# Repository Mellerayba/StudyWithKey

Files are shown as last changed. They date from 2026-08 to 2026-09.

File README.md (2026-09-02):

# StudyWithKey

A custom Bluetooth LE macro remote for flashcard/study-app navigation —
built from a breadboard proof-of-concept through to a battery-powered
custom PCB.

## Status
Currently halted - critical flaw in the ordered PCBs and I am not in a financial position currently to reorder them.
Firmware is completely functional and available to use freely

## Roadmap
- [x] Prototype 1 — breadboard BLE HID proof of concept
- [x] Prototype 2 — custom PCB, USB-C + battery power, hardware complete, DRC clean, ordered
- [ ] Prototype 2 — enclosure (parametric CadQuery model, pending fit check against fabricated board)
- [x] Prototype 2 — firmware (FSM-based button handling, BLE HID)
- [ ] Prototype 3 — ULP RISC-V coprocessor deep-sleep refactor

## Roadmap Update
Sadly the ordered PCB's arrived with a fatal flaw, the switches were miss oriented - causing an internal short circuit. I managed to re - solder some switches 
however it is not viable to do this for the entire order. I am not currently in the financial position to continue this project
after such a set back; however, the firmware is completely functional and available to use on any ESP-32.

## Prototypes
- [Prototype 1: Breadboard](./Physical-Prototypes/README.md) — early proof that BLE HID pairing and keypresses work end to end
- [Prototype 2: Custom PCB](./prototype-2-custom-pcb/) — purpose-built board with USB-C, LiPo charging, and a real power path
- [Physical PCB: Resoldered demo](././Physical-Prototypes/PhysicalProduct.md) — Demo photos and videos of the real custom PCB, showing that the firmware works

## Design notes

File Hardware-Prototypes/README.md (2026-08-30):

# Custom PCB

## Initial PCB prototype

### Hardware Architecture

| Top-Down PCB Layout | 3D Board Preview | Schematic View
| :---: | :---: | :---: |
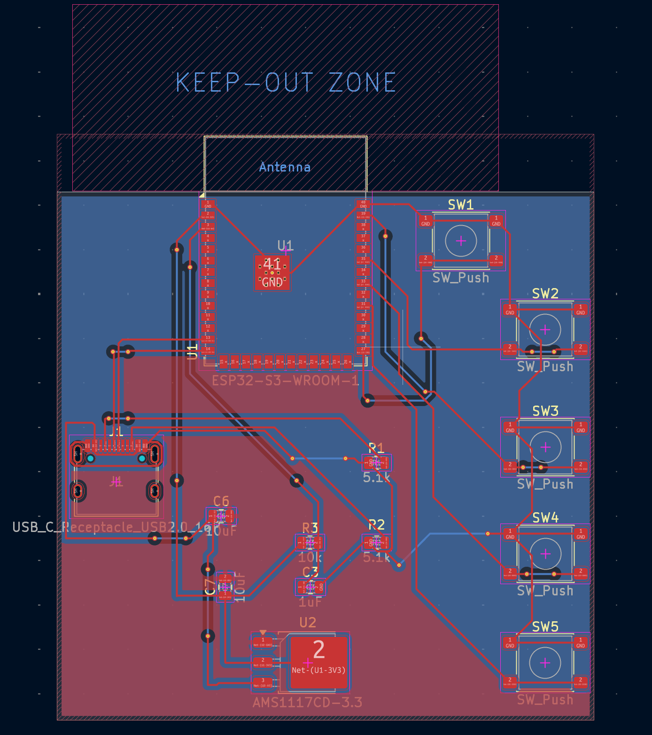
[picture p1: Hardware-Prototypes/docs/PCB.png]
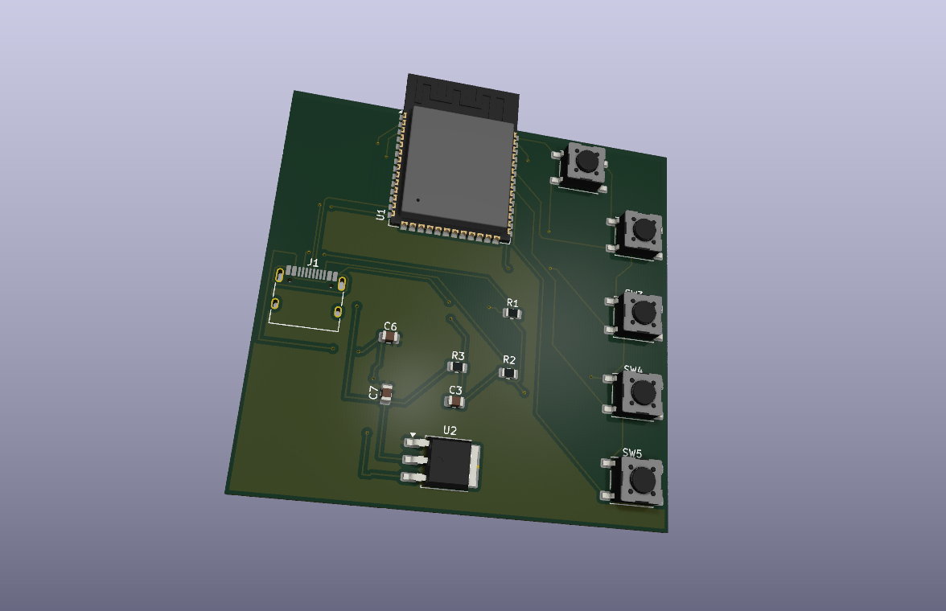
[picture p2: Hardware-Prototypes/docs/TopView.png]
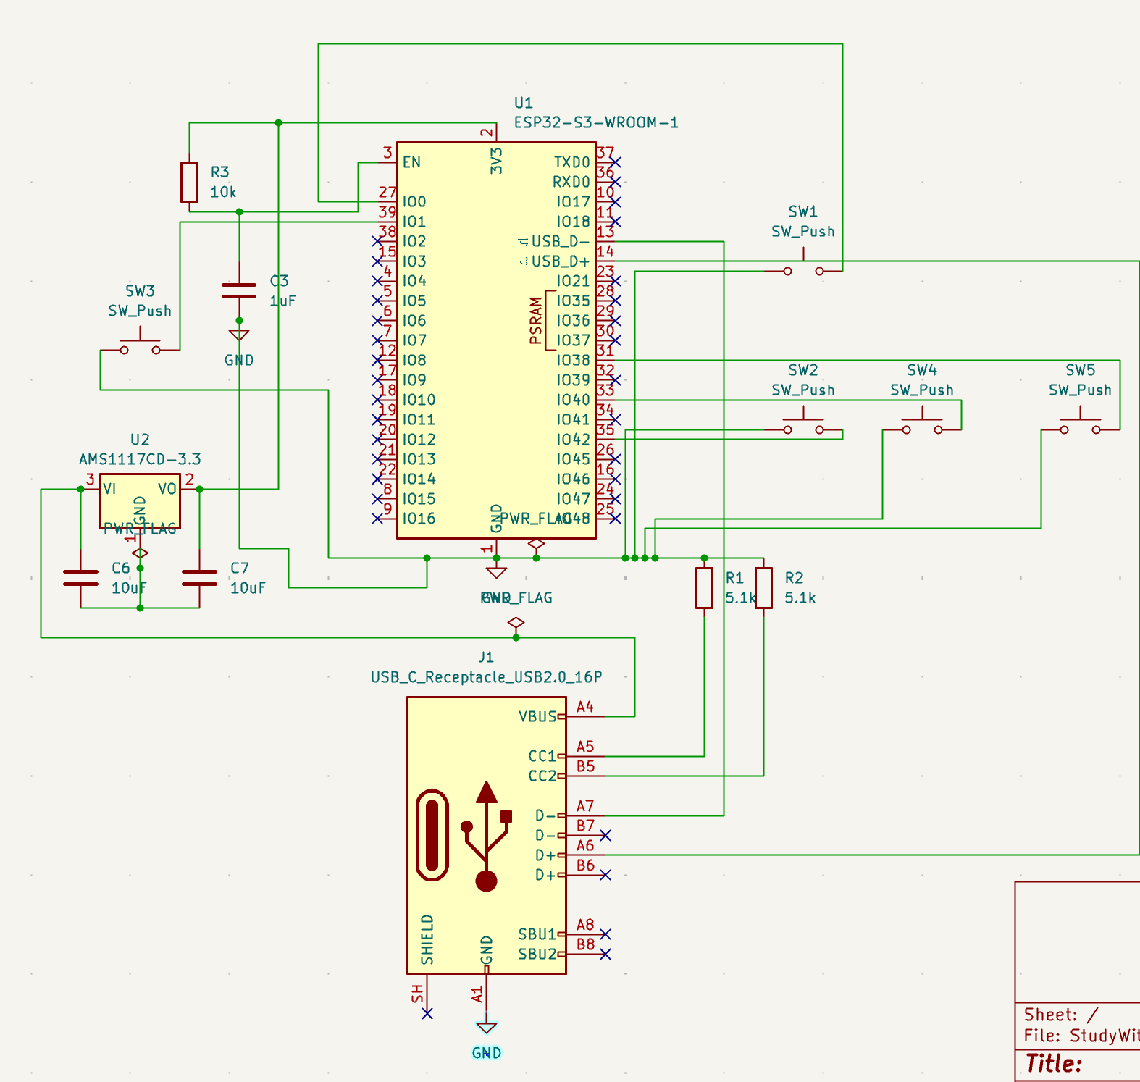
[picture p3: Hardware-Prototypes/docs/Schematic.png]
Schematic
|  |  | 

### Board Specifications
* **Processor:** ESP32-S3-WROOM-1 (Dual-Core Xtensa LX7 + ULP RISC-V Coprocessor)
* **Power Rail:** USB-C (5V) $\rightarrow$ AMS1117-3.3 LDO (3.3V rail with 10µF bulk filtering)
* **Input Matrix:** 5x Tactile Switches (Direct-mapped to RTC GPIOs for low-power deep-sleep wakeups)
* **PCB Constraints:** 2-layer FR-4, 1.6mm board thickness, 1 oz Cu, 0.3mm min via holes

## PCB Prototype 2

| Top-Down PCB Layout | 3D Board Preview | Schematic View
| :---: | :---: | :---: |
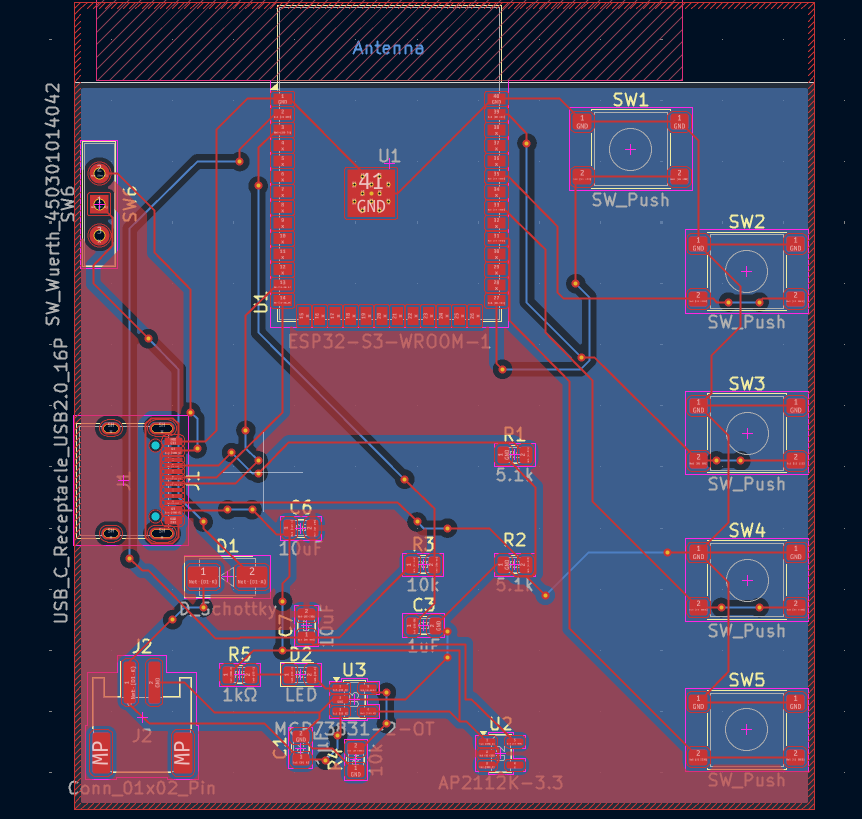
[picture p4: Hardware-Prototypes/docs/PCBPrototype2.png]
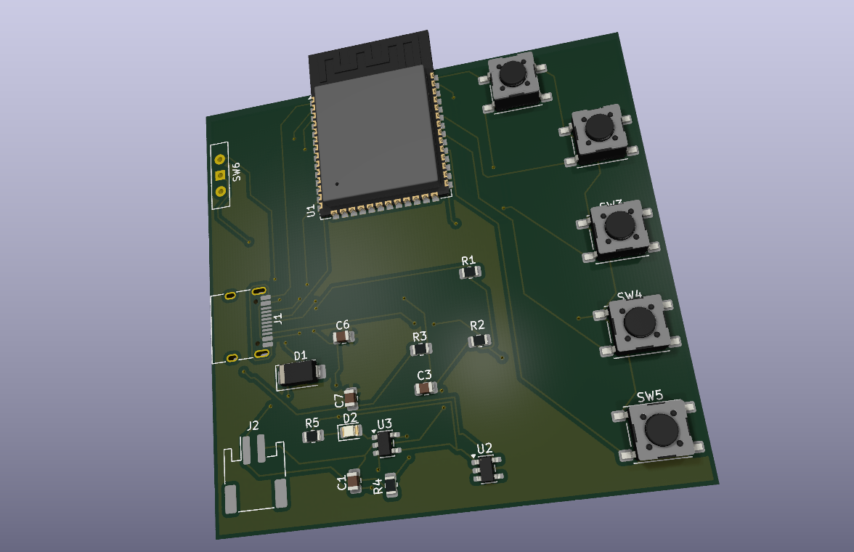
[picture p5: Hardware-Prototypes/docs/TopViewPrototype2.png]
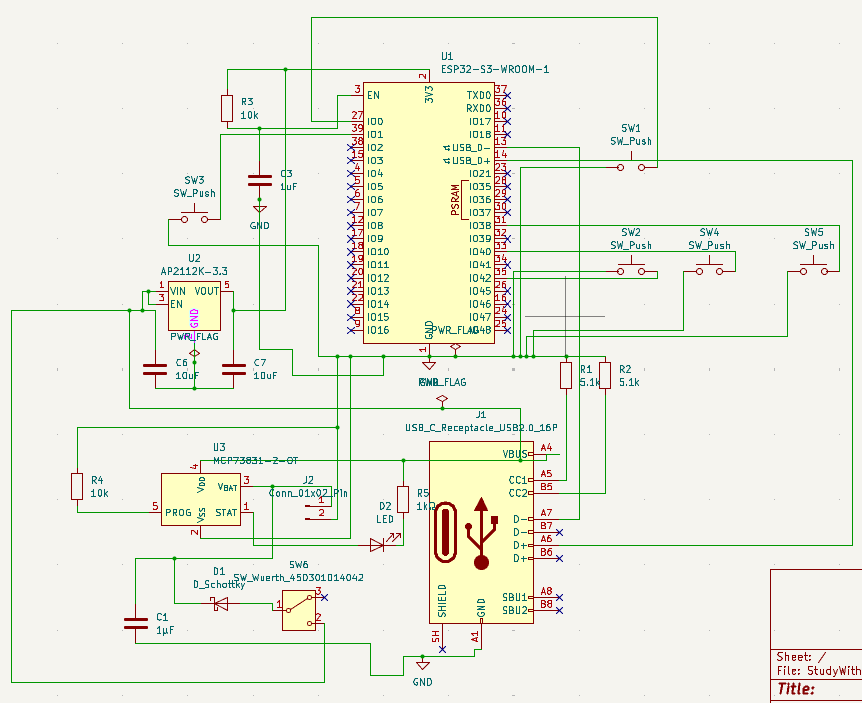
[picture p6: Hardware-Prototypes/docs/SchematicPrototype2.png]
Schematic
|  |  | 

## What changed from Prototype 1
- Custom KiCad schematic + PCB, built around the ESP32-S3-WROOM-1
- USB-C for power/data, with correct CC1/CC2 pull-down resistors for
  UFP detection
- LiPo battery support: MCP73831 charge management, diode-OR'd battery
  feed, and a physical power switch, so the device can run untethered
- 5 macro buttons + a BOOT/download-mode button
- Status LED for charge state

## Design decisions
This section exists because most of the interesting engineering here
was in catching and fixing problems before ordering, not in the first draft.

**Battery power-path safety.** The first version of the power switch
tied the battery directly onto the same net as USB VBUS. That's fine
when only one source is present, but if the device is switched on
*and* plugged into USB simultaneously, USB would backfeed straight
into the battery with no current limiting — a real overcharge/fire
risk once this is something other people are using, not just me.
Fixed with a Schottky diode (SS14) in series with the battery feed,
so current can only flow battery → system, never the reverse.

**Regulator selection.** The original 3.3V regulator (AMS1117) has a
~1.2V dropout — fine for 5V-in USB-only designs, but a single-cell
LiPo spends most of its discharge curve below the ~4.3V that regulator
needs for a clean output. Swapped to the AP2112K-3.3, which has a much
lower dropout (~250mV) and is a proven choice for exactly this LiPo +
USB use case (same part Adafruit uses on their Feather boards).

**Verification process.** Every schematic and PCB revision was checked
with KiCad's ERC/DRC before moving forward, including tracing net
connectivity directly (KiCad's Net Navigator / Highlight Net) rather
than trusting visual inspection alone on a dense schematic — caught
several issues this way that weren't obvious from the drawing (a
reversed status LED wired against the STAT pin's sink-only behaviour,
an isolated ground pour island under the button footprints, and a
button-footprint mixup introduced during a component-shortage
substitution, caught before the gerbers were finalized).

## Status
Schematic and PCB layout complete, DRC clean. Ordered and assembled
via JLCPCB (small first batch). Boards shipped — bring-up and firmware
not yet started.

## Files
- `kicad/` — full KiCad project (schematic + PCB layout)
- `docs/` — BOM, schematic PDF export, gerbers
- `enclosure/` — parametric CadQuery case (see its own README for design notes)

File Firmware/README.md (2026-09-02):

# Firmware

C firmware for the StudyWithKey remote, running on the ESP32-S3-WROOM-1.
Built from a blank ESP-IDF project, staged deliberately so each capability
was proven working in isolation before being combined with the next.

## Status

Core functionality complete and working on hardware.
After power measurements, I found a negligible difference between the built in
C deep sleep module, versus a RISCV deep sleep example code. Therefore, I decided
that it was best to reduce complexity, and not move forward with the RISCV deep 
sleep idea.

## What it does

- Reads 5 physical buttons (4 macro keys + 1 utility) with real
  timestamp-based debouncing, not naive polling
- Presents as a BLE HID keyboard, paired and tested against macOS
- Sends real keypresses: Left Arrow, Right Arrow, Space, H
- Deep sleep after a period of inactivity, waking on button press
- A long-press utility button that clears stored BLE bonding, for
  recovering from stale-pairing issues without a full reflash

## Pin mapping

| Physical pin (WROOM-1) | GPIO | Function |
|---|---|---|
| 27 | GPIO0 | SW1 — long-press: clear BLE bonds and re-advertise |
| 5 | GPIO1 | SW3 — Left Arrow; also the deep-sleep wake source |
| 35 | GPIO42 | SW2 — H |
| 33 | GPIO40 | SW4 — Space |
| 31 | GPIO38 | SW5 — Right Arrow |

GPIO0 and GPIO1 are the only two RTC-capable pins on the ESP32-S3
(GPIO0–21), which is why the wake source specifically has to live on
Left rather than any of the other three macro keys — a hardware
limitation, not a design choice.

## Architecture

Plain C, single source file (`studywithkey-fw.c`) plus the Bluedroid BLE
HID profile files (`hid_dev.c`, `esp_hidd_prf_api.c`, `hid_device_le_prf.c`
and headers), adapted from ESP-IDF's official
`examples/bluetooth/bluedroid/ble/ble_hid_device_demo`.

Each button is tracked with its own pair of state variables — last
accepted level, timestamp of last accepted edge — checked independently
per loop pass. No interrupts; a single polling loop with a short
`vTaskDelay` paces all five checks together.

## Build stages (how this was actually built)

Built and proven in order, each stage verified working before the next
was layered on — deliberately, so any bug found belonged to exactly one
new piece of code, not a tangle of everything at once.

1. **Toolchain + board bring-up** — minimal blank project, confirmed the
   board boots and flashes correctly before writing any real logic.
2. **Single GPIO read, no debouncing** — deliberately naive, to see real
   mechanical switch bounce firsthand before building the fix for it.
3. **Real debouncing** — timestamp-gated edge detection
   (`esp_timer_get_time()`-based), not just a polling delay.
4. **BLE HID pairing proven standalone** — official Bluedroid demo copied
   and run unmodified first, to confirm pairing worked on this hardware
   before any custom code touched it.
5. **All 4 macro buttons wired to real keypresses**, debounce logic
   generalized from one button to four independent trackers.
6. **Deep sleep + wake-on-button**, plus a long-press rebonding utility
   button.
7. **(In progress) ULP-RISC-V** — see below.

## Debugging notes worth keeping

A few bugs found along the way were subtle enough, or generally-useful
enough, to be worth recording rather than just fixing quietly:

- **Floating GPIOs.** Extending debounce from one button to four, the
  `gpio_config()` pin mask was never updated to include the three new
  pins — they were completely unconfigured, no pull-up, genuinely
  floating. Symptom was dramatic (button inputs "spamming" the moment a
  wire touched the pin, with no press involved) but the cause was a
  one-line oversight, not a logic bug.
- **`vTaskDelay` rounding to zero ticks.** FreeRTOS's default tick rate
  is 100Hz (10ms/tick). `pdMS_TO_TICKS(5)` truncates to 0 ticks at that
  rate, meaning the requested "5ms delay" didn't delay at all — the loop
  spun fast enough to starve the idle task and trip the watchdog. Fixed
  by using a delay ≥10ms, since sub-tick delays silently round down
  rather than erroring.
- **Stale BLE bonding after reflashing.** Repeated reflashing during
  development regenerates the device's BLE identity, but macOS keeps the
  previous pairing's keys cached under the same name — producing
  connects that authenticate but then get `GATT_WRITE_NOT_PERMIT`
  errors on notification subscription, with no actual keypresses
  arriving. Fixed by forgetting the device on the Mac and re-pairing
  fresh after every reflash during development; this is also the
  motivating use case for the SW1 rebonding button in the shipped
  firmware.
- **CMake `PRIV_REQUIRES` and `sdkconfig.defaults`.** Merging Bluedroid
  code into a project created via `idf.py create-project` isn't just a
  matter of adding source files — the project's default `sdkconfig` has
  Bluetooth disabled entirely, and no `PRIV_REQUIRES` line can expose
  headers a component hasn't itself enabled. Fixed by copying the real
  `sdkconfig.defaults` from the working example rather than hand-picking
  menuconfig options.

## Open items

- **ULP-RISC-V (cancelled).** The plan is not to replace the
  working `ext0` hardware wake outright, but to evaluate whether a
  ULP-RISC-V debounce stage — confirming a press is sustained before
  waking the main CPU — is worth its own small power cost by preventing
  false full-system wakes from electrical noise. This is being measured,
  not assumed; the honest goal is a repo that says which one actually
  won, not just "used RISC-V because it's impressive."

## Files

- `studywithkey-fw.c` — main application logic
- `hid_dev.c` / `hid_dev.h` — HID report building
- `esp_hidd_prf_api.c` / `esp_hidd_prf_api.h` — HID device profile API
- `hid_device_le_prf.c` / `hidd_le_prf_int.h` — BLE GATT service
  implementation for the HID profile
- `CMakeLists.txt` — component registration, `PRIV_REQUIRES bt nvs_flash
  esp_driver_gpio`
- `sdkconfig.defaults` — Bluetooth/Bluedroid enabled by default

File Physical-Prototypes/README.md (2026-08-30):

# Physical Prototype 1 — Breadboard Proof of Concept
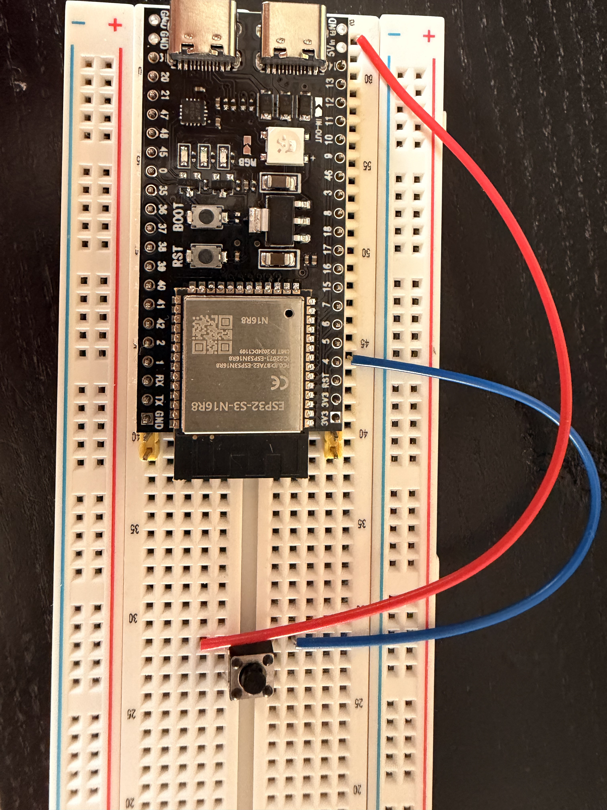
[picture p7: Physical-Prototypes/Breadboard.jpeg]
Breadboard

## What this was
An ESP32 dev board on a breadboard, running modified example BLE HID
keyboard firmware, wired to a handful of push buttons.

## What it proved
- BLE HID pairing and keypress delivery work end to end on this hardware
- Validated the core concept before investing in a custom PCB

## Limitations (by design — this was a spike, not a product)
- Firmware was example code with trivial button-to-keypress mapping,
  no debouncing or state machine
- No power management — always USB-powered, no battery/sleep
- No custom hardware — off-the-shelf dev board only

This prototype's job was to answer one question — "does this concept
work at all?" — before committing time to hardware design. It did,
which is what justified moving to Prototype 2.

# Enclosure - CAD Design

## Case Prototype 1

Parametric, code-generated case for the Prototype 2 PCB — two-part
snap-fit shell, generated with [CadQuery](https://cadquery.readthedocs.io/)
from real board geometry rather than hand-modeled from a datasheet.

## Files

| File | What it is |
|---|---|
| `case_gen.py` | The generator. Every dimension is a named constant at the top — edit and re-run to regenerate both STEP and STL. |
| `case_base.step` / `.stl` | Bottom shell: battery cavity, USB-C cutout, cable channel, snap grooves. |
| `case_lid.step` / `.stl` | Top shell: button holes, slide-switch slot, charge LED hole, engraved wordmark, snap barbs. |

STEP files are for further editing (FreeCAD, Fusion 360). STL files are
print-ready as generated.

## Design notes

- **Board geometry (exact):** pulled directly from the KiCad STEP export
  rather than measured/guessed. Board outline,ESP32 footprint, 
  and all passive heights came from this.
- **Connector/switch/button positions:** the STEP export omits any
  footprint without a bundled 3D model — this includes J1 (USB-C), J2
  (battery connector), and all six switches, since they come from
  easyeda2kicad/generic connector libraries with no STEP model attached.
  Their positions were taken from KiCad's Footprint Properties panel
  instead and converted from mils to the board coordinate
  system used in this script.
- **Retention is snap-fit, not screws.** The PCB has no mounting holes and
  fills its cavity edge-to-edge, so there is no position for a corner
  screw boss that doesn't either sit on top of the board or fall outside
  the case wall — verified by checking the boss radius against the
  available clearance at each corner. Four snap barbs on the lid's
  retaining ring engage grooves in the base wall instead.
- **USB-C cutout is two-stage:** an outer recess sized to the plug's
  moulded housing, then a smaller through-slot for the plug tip. A single
  flush rectangular hole would have left the wall too
  thick for a plug to seat or latch.
- **SW6 (slide switch) opening is in the lid, not the side wall** — the
  ALPS SSSS912000 is top-actuated, so the case has to be actuated from
  above, not from the edge.
- **Height stack-up is set by J2, not the buttons.** The JST-PH connector
  stands taller than the 6×6×4.3mm tactile switches, so it determines the
  internal clearance and overall case height.

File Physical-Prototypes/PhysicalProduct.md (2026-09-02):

# Physical Product

| Xray | Physical PCB | Problem
| :---: | :---: | :---: |
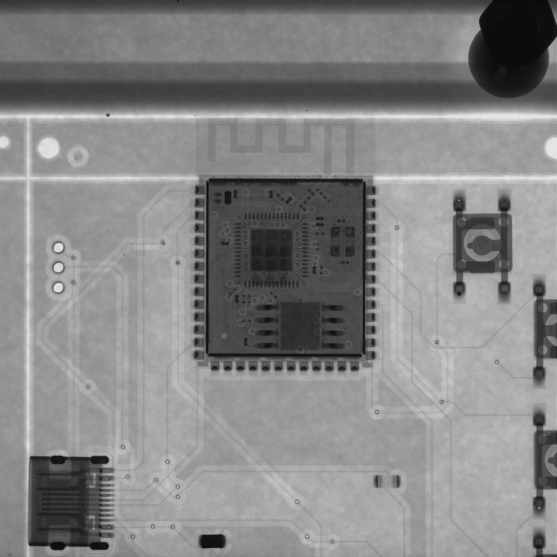
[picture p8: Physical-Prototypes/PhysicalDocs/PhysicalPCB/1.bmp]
PCB Xray
|  | Physical PCB | Problem

When the boards arrived, I attempted to flash my firmware, however each time I did so, it got stuck on "waiting for download"

So I tested with my multimeter. The conclusions from this were that GPIO0 from pin 27 was physically shorted to the ground. Hence the
chip was stuck in boot mode constantly.
I managed to find the culprit. The resistance of pin 27 was around 0.3 Ohms when the board was powered, however when the switch was pressed 
this didn't change. That was when I came to the realisation that I had made a complete oversight in the design of my PCB.

I had connected the same sides of the buttons to the ground and to the chip, without knowing which orientation the button was going to be in.
This meant that every single button on the board was shorted to the ground. 

I didn't let this large setback get me down, I grabbed my soldering iron, and physically re-soldered the buttons on the board in an aim to 
prove that my firmware worked. After re-soldering, my firmware flashed successfully and I ended up with a temperamental, but working product.

Sadly, the journey ends here for now; however, I have learnt many valuable lessons with my first hardware build - most importantly, do not wire 
a switch on the same sides.

| Testing | Soldering
| :---: | :---: |
| Testing | Soldering

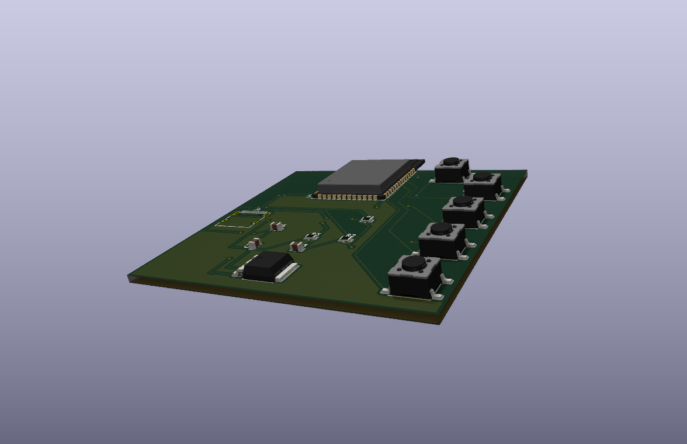
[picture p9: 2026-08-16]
Hardware-Prototypes/docs/SideView.png

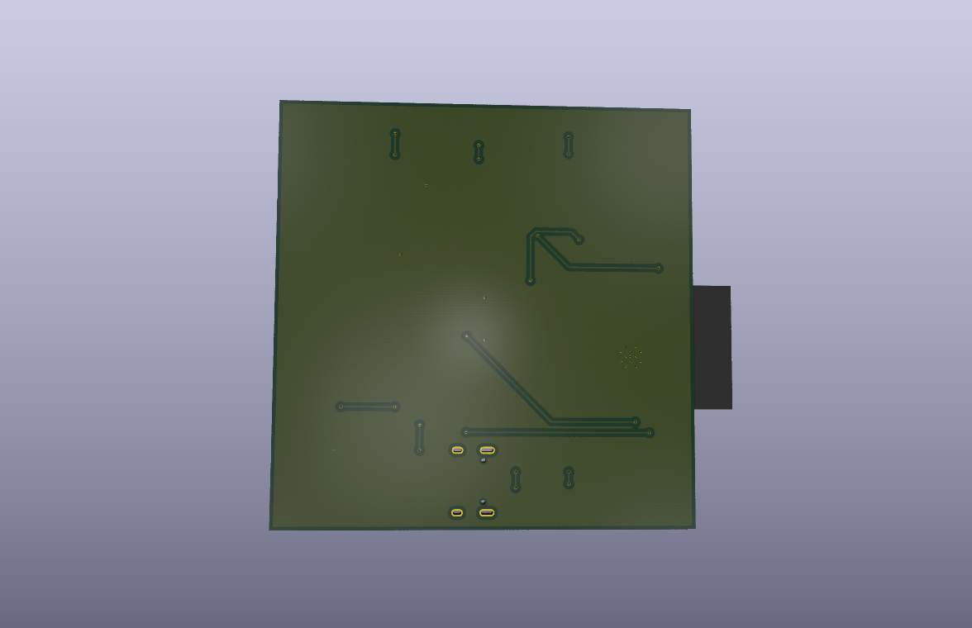
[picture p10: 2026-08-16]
Hardware-Prototypes/docs/UndersideView.png

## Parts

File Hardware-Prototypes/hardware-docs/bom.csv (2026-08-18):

Designator | Footprint | Quantity | Value | LCSC Part #
C3 | 0805 | 1 | 1uF
C6, C7 | 0805 | 2 | 10uF
J1 | USB_C_Receptacle_HRO_TYPE-C-31-M-12 | 1 | USB_C_Receptacle_USB2.0_16P
R1, R2 | 0805 | 2 | 5.1k
R3 | 0805 | 1 | 10k
SW1, SW2, SW3, SW4, SW5 | SW_SPST_PTS645Sx43SMTR92 | 5 | SW_Push
U1 | ESP32-S3-WROOM-1 | 1 | ESP32-S3-WROOM-1
U2 | TO-252-3_TabPin2 | 1 | AMS1117CD-3.3

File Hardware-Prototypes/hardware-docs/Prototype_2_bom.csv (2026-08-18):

Designator | Footprint | Quantity | Value | LCSC Part #
C1 | 0805 | 1 | 1µF
C3 | 0805 | 1 | 1uF
C6, C7 | 0805 | 2 | 10uF
D1 | D_SMA | 1 | D_Schottky
D2 | 0805 | 1 | LED
J1 | USB_C_Receptacle_HRO_TYPE-C-31-M-12 | 1 | USB_C_Receptacle_USB2.0_16P
J2 | JST_PH_S2B-PH-SM4-TB_1x02-1MP_P2.00mm_Horizontal | 1 | Conn_01x02_Pin
R1, R2 | 0805 | 2 | 5.1k
R3, R4 | 0805 | 2 | 10k
R5 | 0805 | 1 | 1kΩ
SW1, SW2, SW3, SW4, SW5 | SW_SPST_PTS645Sx43SMTR92 | 5 | SW_Push
SW6 | SW_Slide-03_Wuerth-WS-SLTV_10x2.5x6.4_P2.54mm | 1 | SW_Wuerth_450301014042
U1 | ESP32-S3-WROOM-1 | 1 | ESP32-S3-WROOM-1
U2 | SOT-23-5 | 1 | AP2112K-3.3
U3 | SOT-23-5 | 1 | MCP73831-2-OT

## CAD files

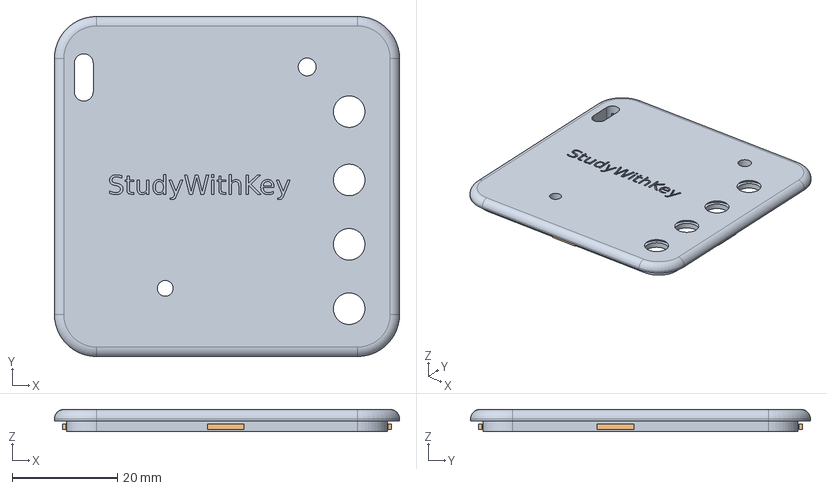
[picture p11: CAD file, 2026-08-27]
Physical-Prototypes/PhysicalDocs/CasePrototype1/case_lid.step
65.7 x 64.7 x 4.20 mm

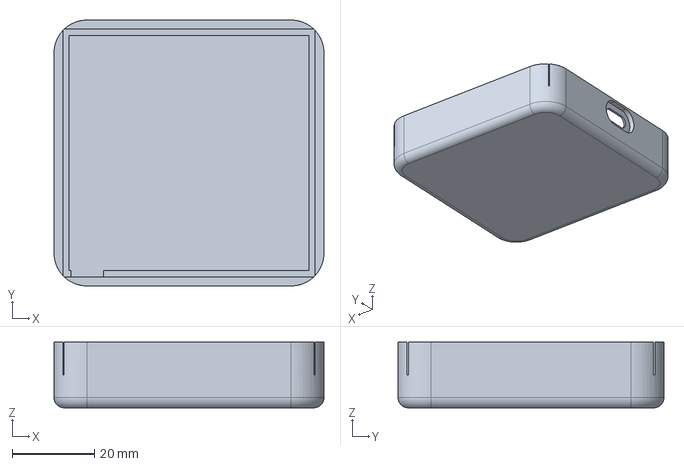
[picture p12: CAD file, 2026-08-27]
Physical-Prototypes/PhysicalDocs/CasePrototype1/case_base.step
65.7 x 64.7 x 16.0 mm

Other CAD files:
Physical-Prototypes/PhysicalDocs/CasePrototype1/case_base.stl
Physical-Prototypes/PhysicalDocs/CasePrototype1/case_lid.stl

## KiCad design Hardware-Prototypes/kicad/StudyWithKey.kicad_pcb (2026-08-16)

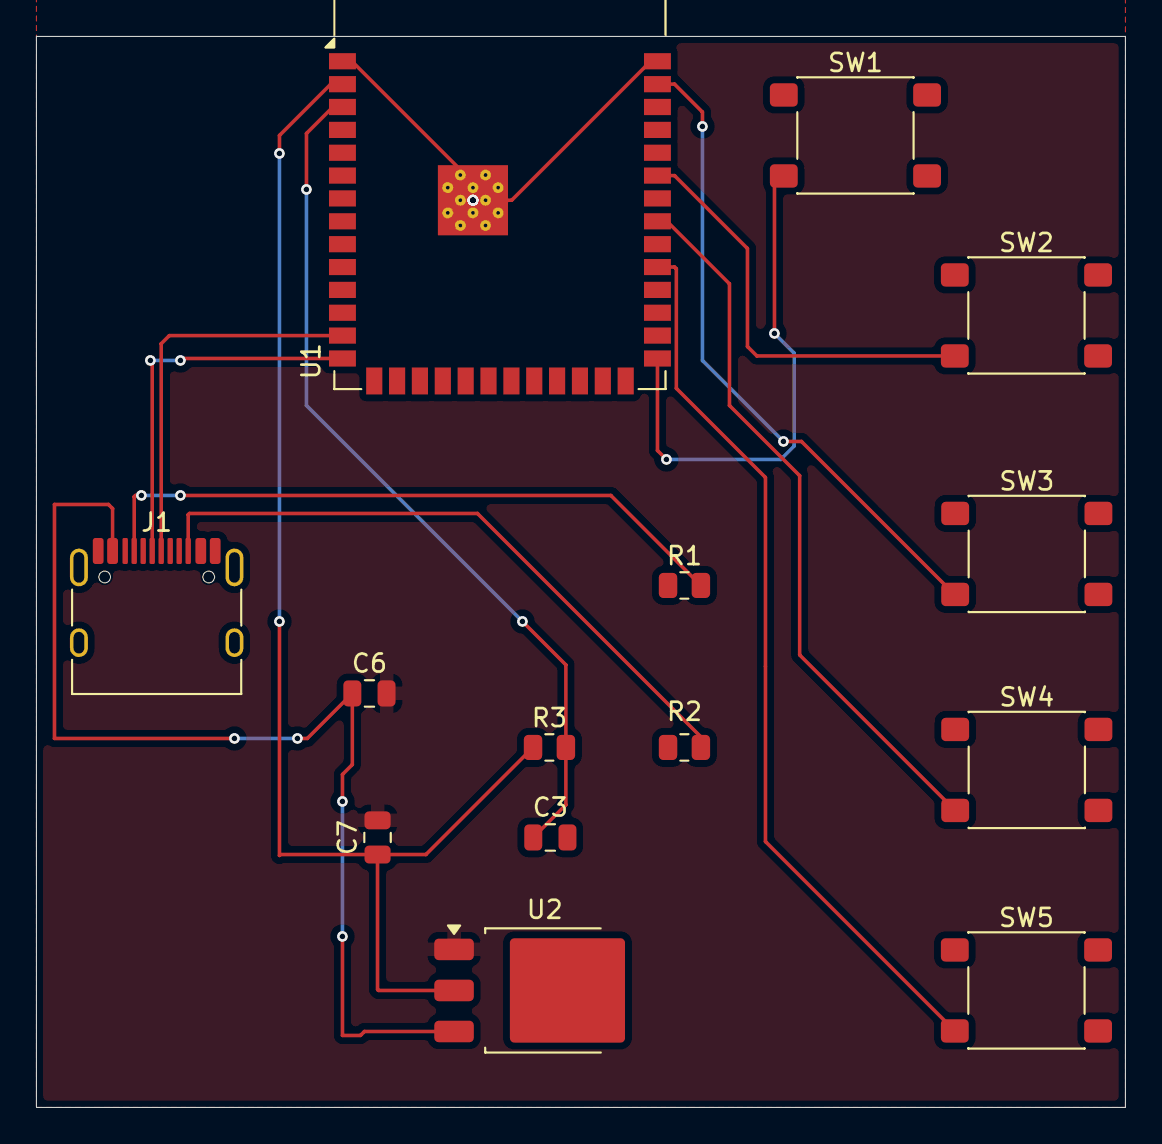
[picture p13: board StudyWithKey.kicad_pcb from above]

Board: 2 copper layers, 60.5 x 59.5 mm, 14 parts (0 on the bottom side), 14 nets.

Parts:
C3: 1uF; C_0805_2012Metric
C6, C7: 10uF; C_0805_2012Metric
J1: USB_C_Receptacle_USB2.0_16P; USB_C_Receptacle_HRO_TYPE-C-31-M-12
R1, R2: 5.1k; R_0805_2012Metric
R3: 10k; R_0805_2012Metric
SW1, SW2, SW3, SW4, SW5: SW_Push; SW_SPST_PTS645Sx43SMTR92
U1: ESP32-S3-WROOM-1
U2: AMS1117CD-3.3; TO-252-3_TabPin2

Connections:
GND: C3.2, R1.1, R2.1, SW1.1, SW2.1, SW3.1, SW4.1, SW5.1, U1.1 (GND), U1.40 (GND), U1.41 (GND)
unnamed: J1.A5 (CC1), R1.2
unnamed: J1.B5 (CC2), R2.2
unnamed: C7.1, R3.1, U1.2 (3V3), U2.2 (VO)
unnamed: C3.1, R3.2, U1.3 (EN)
unnamed: SW1.2, U1.27 (IO0)
unnamed: SW3.2, U1.39 (IO1)
unnamed: SW5.2, U1.31 (IO38)
unnamed: SW4.2, U1.33 (IO40)
unnamed: SW2.2, U1.35 (IO42)
unnamed: J1.A6 (D+), U1.14 (USB_D+)
unnamed: J1.A7 (D-), U1.13 (USB_D-)
unnamed: C6.2, C7.2, U2.1 (GND)
unnamed: C6.1, J1.A4 (VBUS), J1.A9 (VBUS), J1.B4 (VBUS), J1.B9 (VBUS), U2.3 (VI)

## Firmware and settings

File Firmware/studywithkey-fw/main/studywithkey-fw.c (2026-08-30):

#include <stdio.h>
#include "freertos/FreeRTOS.h"
#include "freertos/task.h"
#include "driver/gpio.h"
#include "esp_log.h"
#include "esp_timer.h"
#include "esp_bt.h"
#include "esp_bt_main.h"
#include "esp_bt_device.h"
#include "esp_bt_defs.h"
#include "esp_gap_ble_api.h"
#include "esp_gatts_api.h"
#include "esp_gatt_defs.h"
#include "esp_hidd_prf_api.h"
#include "hid_dev.h"
#include "nvs_flash.h"
#include "esp_sleep.h"
#include "driver/rtc_io.h"

#define KEY_H_GPIO      GPIO_NUM_42   // SW2
#define KEY_LEFT_GPIO   GPIO_NUM_1    // SW3
#define KEY_SPACE_GPIO  GPIO_NUM_40   // SW4
#define KEY_RIGHT_GPIO  GPIO_NUM_38   // SW5
#define KEY_RECONNECT_GPIO GPIO_NUM_0 // SW1

static const char *TAG = "swk";

static uint16_t hid_conn_id = 0;
static bool sec_conn = false;

#define HIDD_DEVICE_NAME "StudyWithKey"
static uint8_t hidd_service_uuid128[] = {
    0xfb, 0x34, 0x9b, 0x5f, 0x80, 0x00, 0x00, 0x80, 0x00, 0x10, 0x00, 0x00, 0x12, 0x18, 0x00, 0x00,
};

static esp_ble_adv_data_t hidd_adv_data = {
    .set_scan_rsp = false,
    .include_name = true,
    .include_txpower = true,
    .min_interval = ESP_BLE_GAP_CONN_ITVL_MS(7.5),
    .max_interval = ESP_BLE_GAP_CONN_ITVL_MS(20),
    .appearance = 0x03c0,
    .manufacturer_len = 0,
    .p_manufacturer_data = NULL,
    .service_data_len = 0,
    .p_service_data = NULL,
    .service_uuid_len = sizeof(hidd_service_uuid128),
    .p_service_uuid = hidd_service_uuid128,
    .flag = 0x6,
};

static esp_ble_adv_params_t hidd_adv_params = {
    .adv_int_min = ESP_BLE_GAP_ADV_ITVL_MS(20),
    .adv_int_max = ESP_BLE_GAP_ADV_ITVL_MS(30),
    .adv_type = ADV_TYPE_IND,
    .own_addr_type = BLE_ADDR_TYPE_PUBLIC,
    .channel_map = ADV_CHNL_ALL,
    .adv_filter_policy = ADV_FILTER_ALLOW_SCAN_ANY_CON_ANY,
};

static void hidd_event_callback(esp_hidd_cb_event_t event, esp_hidd_cb_param_t *param)
{
    switch (event) {
        case ESP_HIDD_EVENT_REG_FINISH:
            if (param->init_finish.state == ESP_HIDD_INIT_OK) {
                esp_ble_gap_set_device_name(HIDD_DEVICE_NAME);
                esp_ble_gap_config_adv_data(&hidd_adv_data);
            }
            break;
        case ESP_HIDD_EVENT_BLE_CONNECT:
            ESP_LOGI(TAG, "BLE connect");
            hid_conn_id = param->connect.conn_id;
            break;
        case ESP_HIDD_EVENT_BLE_DISCONNECT:
            sec_conn = false;
            ESP_LOGI(TAG, "BLE disconnect");
            esp_ble_gap_start_advertising(&hidd_adv_params);
            break;
        default:
            break;
    }
}

static void clear_all_bonds(void)
{
    int dev_num = esp_ble_get_bond_device_num();
    if (dev_num == 0) return;

    esp_ble_bond_dev_t *dev_list = malloc(sizeof(esp_ble_bond_dev_t) * dev_num);
    esp_ble_get_bond_device_list(&dev_num, dev_list);
    for (int i = 0; i < dev_num; i++) {
        esp_ble_remove_bond_device(dev_list[i].bd_addr);
    }
    free(dev_list);
    ESP_LOGI(TAG, "Cleared %d bonded device(s)", dev_num);
}

static void gap_event_handler(esp_gap_ble_cb_event_t event, esp_ble_gap_cb_param_t *param)
{
    switch (event) {
        case ESP_GAP_BLE_ADV_DATA_SET_COMPLETE_EVT:
            esp_ble_gap_start_advertising(&hidd_adv_params);
            break;
        case ESP_GAP_BLE_SEC_REQ_EVT:
            esp_ble_gap_security_rsp(param->ble_security.ble_req.bd_addr, true);
            break;
        case ESP_GAP_BLE_AUTH_CMPL_EVT:
            ESP_LOGI(TAG, "pair status = %s",
                     param->ble_security.auth_cmpl.success ? "success" : "fail");
            if (param->ble_security.auth_cmpl.success) {
                sec_conn = true;
            }
            break;
        default:
            break;
    }
}



void app_main(void)
{
    esp_sleep_wakeup_cause_t cause = esp_sleep_get_wakeup_cause();
    esp_err_t ret = nvs_flash_init();
    if (ret == ESP_ERR_NVS_NO_FREE_PAGES || ret == ESP_ERR_NVS_NEW_VERSION_FOUND) {
        ESP_ERROR_CHECK(nvs_flash_erase());
        ret = nvs_flash_init();
    }
    ESP_ERROR_CHECK(ret);

    ESP_ERROR_CHECK(esp_bt_controller_mem_release(ESP_BT_MODE_CLASSIC_BT));

    esp_bt_controller_config_t bt_cfg = BT_CONTROLLER_INIT_CONFIG_DEFAULT();
    ESP_ERROR_CHECK(esp_bt_controller_init(&bt_cfg));
    ESP_ERROR_CHECK(esp_bt_controller_enable(ESP_BT_MODE_BLE));

    esp_bluedroid_config_t bd_cfg = BT_BLUEDROID_INIT_CONFIG_DEFAULT();
    ESP_ERROR_CHECK(esp_bluedroid_init_with_cfg(&bd_cfg));
    ESP_ERROR_CHECK(esp_bluedroid_enable());

    ESP_ERROR_CHECK(esp_hidd_profile_init());

    esp_ble_gap_register_callback(gap_event_handler);
    esp_hidd_register_callbacks(hidd_event_callback);

    esp_ble_auth_req_t auth_req = ESP_LE_AUTH_BOND;
    esp_ble_io_cap_t iocap = ESP_IO_CAP_NONE;
    uint8_t key_size = 16;
    uint8_t init_key = ESP_BLE_ENC_KEY_MASK | ESP_BLE_ID_KEY_MASK;
    uint8_t rsp_key = ESP_BLE_ENC_KEY_MASK | ESP_BLE_ID_KEY_MASK;
    esp_ble_gap_set_security_param(ESP_BLE_SM_AUTHEN_REQ_MODE, &auth_req, sizeof(uint8_t));
    esp_ble_gap_set_security_param(ESP_BLE_SM_IOCAP_MODE, &iocap, sizeof(uint8_t));
    esp_ble_gap_set_security_param(ESP_BLE_SM_MAX_KEY_SIZE, &key_size, sizeof(uint8_t));
    esp_ble_gap_set_security_param(ESP_BLE_SM_SET_INIT_KEY, &init_key, sizeof(uint8_t));
    esp_ble_gap_set_security_param(ESP_BLE_SM_SET_RSP_KEY, &rsp_key, sizeof(uint8_t));
    gpio_config_t io_conf = {
        .pin_bit_mask = (1ULL << KEY_LEFT_GPIO) | (1ULL << KEY_RIGHT_GPIO) | (1ULL << KEY_SPACE_GPIO) | (1ULL << KEY_H_GPIO) | (1ULL << KEY_RECONNECT_GPIO),
        .mode = GPIO_MODE_INPUT,
        .pull_up_en = GPIO_PULLUP_ENABLE,
        .pull_down_en = GPIO_PULLDOWN_DISABLE,
        .intr_type = GPIO_INTR_DISABLE,
    };
    gpio_config(&io_conf);


    int64_t timeoutLast = 0;
    
    int64_t reconnectLast = 0;

    bool reconnectCheck = false;

    int leftOutput = 1;
    int64_t leftLast = 0;

    int rightOutput = 1;
    int64_t rightLast = 0;
    //Individual trackers for the 4 buttons
    int spaceOutput = 1;
    int64_t spaceLast = 0;

    int hOutput = 1;
    int64_t hLast = 0;
    ESP_LOGI(TAG, "Stage 3: watching all, with debouncing");

    while (1) {
        //Reconnect key check
        int reconnectLevel =  gpio_get_level(KEY_RECONNECT_GPIO);
        if(reconnectCheck){
            if(reconnectLevel == 0){
                if(esp_timer_get_time() > reconnectLast + 3000000){
                    clear_all_bonds();
                    reconnectCheck = false;
                }
            }
            else{
                reconnectCheck = false;
            }
        }
        if (reconnectLevel == 0 && reconnectCheck == false){
                reconnectCheck = true;
                reconnectLast = esp_timer_get_time();
            }
        

        vTaskDelay(pdMS_TO_TICKS(10)); //Prevent running at clock speed 
        if(esp_timer_get_time() > timeoutLast + 60000000){
            rtc_gpio_pullup_en(GPIO_NUM_1);
            rtc_gpio_pulldown_dis(GPIO_NUM_1);
            esp_sleep_enable_ext0_wakeup(GPIO_NUM_1, 0);
            esp_deep_sleep_start();
        }
        //Left key check
        int Leftlevel = gpio_get_level(KEY_LEFT_GPIO);
        if (!(Leftlevel == leftOutput || esp_timer_get_time()-leftLast < 30000)) {
            leftOutput = Leftlevel;
            if(leftOutput == 0){
                ESP_LOGI(TAG, "Left button pressed");
                if (sec_conn) {
                uint8_t key_code = HID_KEY_LEFT_ARROW;
                esp_hidd_send_keyboard_value(hid_conn_id, 0, &key_code, 1);
                vTaskDelay(100 / portTICK_PERIOD_MS);
                esp_hidd_send_keyboard_value(hid_conn_id, 0, NULL, 0); // Release key
                }
            }
            timeoutLast = esp_timer_get_time();
            leftLast = esp_timer_get_time();
        }


        //Right key check
        int Rightlevel = gpio_get_level(KEY_RIGHT_GPIO);
        if (!(Rightlevel == rightOutput || (esp_timer_get_time()-rightLast < 30000))) {
            rightOutput = Rightlevel;
            if(rightOutput == 0){
                ESP_LOGI(TAG, "Right button pressed");
                if (sec_conn) {
                uint8_t key_code = HID_KEY_RIGHT_ARROW;
                esp_hidd_send_keyboard_value(hid_conn_id, 0, &key_code, 1);
                vTaskDelay(100 / portTICK_PERIOD_MS);
                esp_hidd_send_keyboard_value(hid_conn_id, 0, NULL, 0); // Release key
                }
            }
            rightLast = esp_timer_get_time();
            timeoutLast = esp_timer_get_time();
        }



        //Space key check
        int Spacelevel = gpio_get_level(KEY_SPACE_GPIO);
        if (!(Spacelevel == spaceOutput || (esp_timer_get_time()-spaceLast < 30000))) {
            spaceOutput = Spacelevel;
            if(spaceOutput == 0){
                ESP_LOGI(TAG, "Space button pressed");
                if (sec_conn) {
                uint8_t key_code = HID_KEY_SPACEBAR;
                esp_hidd_send_keyboard_value(hid_conn_id, 0, &key_code, 1);
                vTaskDelay(100 / portTICK_PERIOD_MS);
                esp_hidd_send_keyboard_value(hid_conn_id, 0, NULL, 0); // Release key
                }
            }
            spaceLast = esp_timer_get_time();
            timeoutLast = esp_timer_get_time();
        }

        //H key check
        int Hlevel = gpio_get_level(KEY_H_GPIO);
        if (!(Hlevel == hOutput || (esp_timer_get_time()-hLast < 30000))){
            hOutput = Hlevel;
            if(hOutput == 0){
                ESP_LOGI(TAG, "H button pressed");
                if (sec_conn) {
                uint8_t key_code = HID_KEY_H;
                esp_hidd_send_keyboard_value(hid_conn_id, 0, &key_code, 1);
                vTaskDelay(100 / portTICK_PERIOD_MS);
                esp_hidd_send_keyboard_value(hid_conn_id, 0, NULL, 0); // Release key
                }
            }
            hLast = esp_timer_get_time();
            timeoutLast = esp_timer_get_time();
        }

    }
}

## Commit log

2026-08-16 Added docs folder for hardware images
    [Schematic.kicad_sch]
2026-08-16 Added hardware KCAD files to repo
    [StudyWithKey-B_Cu.gbr, StudyWithKey-B_Mask.gbr, StudyWithKey-B_Paste.gbr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]
2026-08-18 Added files for prototype 2
    [New_bom.csv, New_designators.csv, New_positions.csv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]
2026-08-18 Adjusted file structure
    [New_bom.csv, New_designators.csv, New_positions.csv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]
2026-08-18 Added folder and evidence of firt physical prototype
2026-08-18 Update README.md for prototype 2
2026-08-18 Added README.md for physical prototypes
2026-08-27 Updated directory for PCB xray and case prototype
    [case_base.step, case_base.stl, case_lid.step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]
2026-08-27 Update README.md for CAD design
2026-08-30 First Firmware commit - button with debouncing in C
2026-08-30 Complete C firmware for PCB
2026-08-30 Added ble reset button for SW1 (iopin0)
2026-08-31 Added power measurements
2026-08-31 Updated read me for battery life calculations
